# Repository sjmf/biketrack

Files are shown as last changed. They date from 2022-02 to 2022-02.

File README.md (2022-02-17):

# BikeTrack
A homebrew GPS Tracker using Teensy 3.x and SIM808.

This project aims to implement a basic GPS tracker with the above hardware. There
is a requirement that this runs from a battery, potentially using the bike dynamo 
to charge while riding.

In 2020 my bike was stolen from the roof of my car. Although I later found where it
was located, due to police incompetence it still has not been recovered. I bought
a new bike, and set about building an asset tracker with electronics hobbyist parts.

This repository contains WIP code and associated files for a basic asset tracking
system using GPS. As a work-in-progress, it is something I am tinkering with in
my spare time. While I'm good at finishing projects, I also tend to underestimate
the timescales and labour required to get there, so recognise the idiom that the 
last 10% takes 90% of the time...

## Hardware Selection
I received the [Adafruit SIM808](https://learn.adafruit.com/adafruit-fona-808-cellular-plus-gps-breakout/overview)
as a thoughtful christmas gift from my partner. I had a Teensy 3.1 in my electronics
storage, hence the selection of this microcontroller. The Sparkfun [MMA8452Q Accelerometer](https://www.sparkfun.com/products/12756)
was the only part I've had to actually buy so far!

The current status of this hardware is breadboarded up. Firmware is under implemetation.
The plan is to design and fabricate a simple PCB to solder these components directly on to, 
and 3d-print a housing/case using my [Prusa Mini+](https://www.prusa3d.com/product/original-prusa-mini-8/).

## Project Roadmap

- [x] Hardware Selection
  - [x] [Teensy 3.x](https://www.pjrc.com/store/teensy32.html)
  - [x] [Adafruit SIM808](https://learn.adafruit.com/adafruit-fona-808-cellular-plus-gps-breakout/overview)
  - [x] [MMA8452Q Accelerometer](https://www.sparkfun.com/products/12756)
- [ ] Firmware Implementation (breadboard)
  - [x] SIM808 [Proof of Concept](https://forums.adafruit.com/viewtopic.php?f=54&t=187767&p=910403)
    - [x] Power on programatically using KEY pin
    - [x] Cellular + GPS functionality
    - [x] Run from battery
  - [x] MMA8452Q Proof of Concept
    - [x] Interrupt-driven code PoC ([modified SparkFun Library](https://github.com/sjmf/SparkFun_MMA8452Q_Arduino_Library))
  - [ ] Low Power use on Teensy using [duff2013/Snooze](https://github.com/duff2013/Snooze)
  - [ ] Code Integration (see [Firmware Requirements](Requirements.md))
- [ ] Hardware implementation
  - [x] Breadboard PoC
  - [x] Schematic design
  - [x] PCB Design / Layout
  - [x] Order PCBs
  - [ ] Solder up
- [x] Serverside functionality
  - [x] SIM808 POST to server
  - [x] Store GPS points in [MongoDB Atlas](https://www.mongodb.com/cloud/atlas/)
  - [x] Retrieve GPX Track
  - [x] Plot GPX track in OpenLayers
  - [ ] Security (currently no authentication, no client SSL, replay attacks possible)
  - [ ] Add field 'segmentstart' to new track segments when storing
- [ ] Housing design
  - [ ] CAD housing for project
  - [ ] 3D-print case

## Gallery

Hardware progress. The devices on a breadboard:
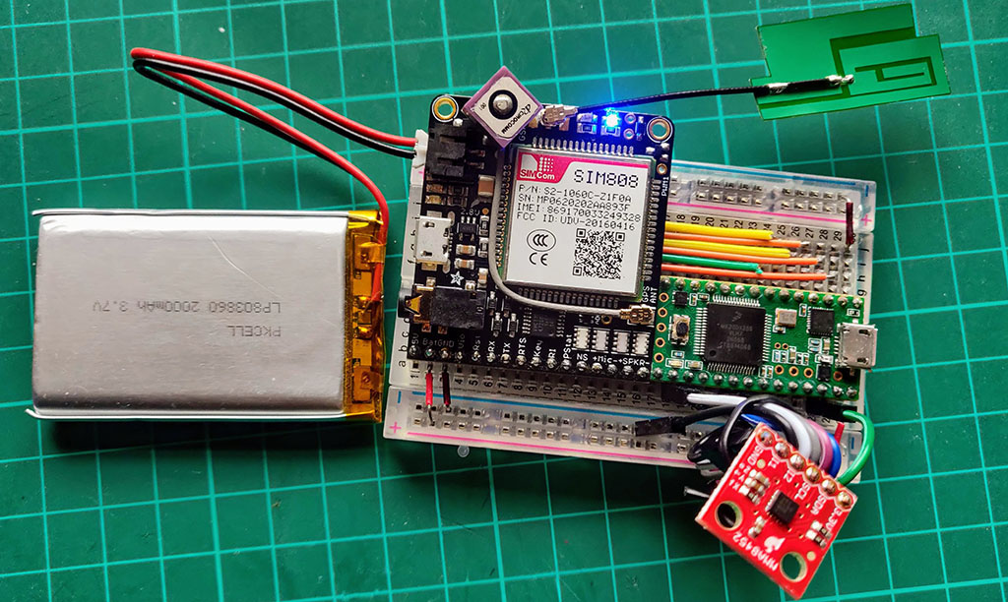
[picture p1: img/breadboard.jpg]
The tracker hardware on an electronics breadboard


Learning [Fusion 360](https://www.autodesk.co.uk/products/fusion-360/personal):
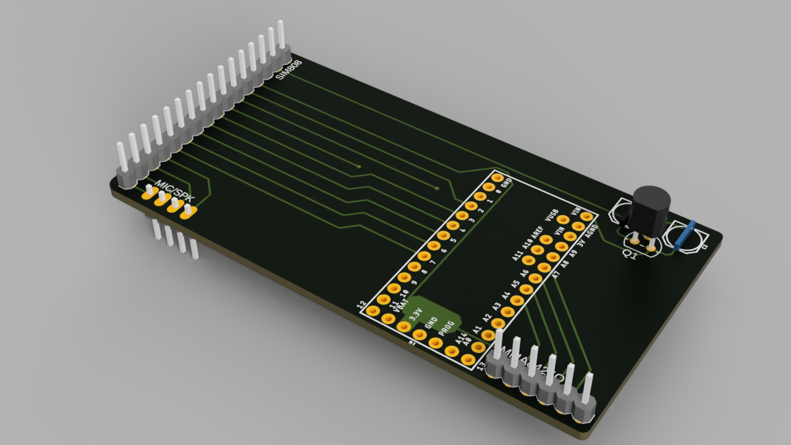
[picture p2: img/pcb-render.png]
A CAD rendering of the PCB


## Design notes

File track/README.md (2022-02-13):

# Server-side example application

This directory contains an example application in PHP, using Composer to 
install the [MongoDB Library](https://docs.mongodb.com/drivers/php/).
View the documentation at that link to install it, as it requires a low-level
API extension to be installed in your PHP CGI server.

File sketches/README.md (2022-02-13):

# Arduino sketches
Proof-of-concept and implementation Arduino sketches for the FONA and
accelerometer hardware.

## accel-interrupt
Uses a modified Sparkfun Library to read the MMA8452Q via the interrupt pin.
Install this library from [sjmf/SparkFun_MMA8452Q_Arduino_Library](https://github.com/sjmf/SparkFun_MMA8452Q_Arduino_Library)
by downloading it as a zip file, then click "Sketch > Include Library > Add .ZIP Library..."
within Teensyduino. Note that this lib acts as a replacement and will conflict with the original
Sparkfun Lib.

## track-gps
A basic implementation of the GPS tracking functionality using a state machine

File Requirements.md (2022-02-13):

# Firmware Requirements

This project needs to be low-power, low-data, and somewhat resilient. As such, this document examines
the firmware requirements needed to achieve this.

There are two modes of operation: low-accuracy, and high-accuracy.

__Low accurracy__ mode is when we've detected no movement. We're just letting the server know we're still here, and our battery level.
We may want a number of tries to get a GPS fix, and if we fail, just get gsmLoc instead. Then, send the battery level and go back to sleep.

__High accuracy__ mode is when we're moving. A second timer interrupt is configured to upload movement every 30s(~?). Keep all radios on!

## Setup
At setup, we do the following:

 - Initialise pins: set pinModes for I/O on FONA and Accelerometer
 - Hardware check. Are the peripherals present?
 - Hardware initialisation: run initialisation routines
 - Initialise interrupts: attachInterrupt for timers and accelerometer

## Main loop

Most of the time, we want to deep-sleep here.

The sleep will be interrupted and the loop will run when the following happens:

 - A timer interrupt happened
 - Movement happened

## States
Build a [transition table](https://www.adamtornhill.com/Patterns%20in%20C%202,%20STATE.pdf) for our state machine.

States to cover:

 - Trying to get first GPS fix
 - Got GPS first fix (have GPSdata)
 - Turn on GPRS radio (don't advance until active)
 - Transmit current position over HTTP
 - Shut down GPRS radio

We will want to keep the GPRS radio on while movement is happening.

## Interrupts

### Timers

It's time to wake up and check we have a fix. If we do, then upload that.

### Accelerometer movement

Sets the current time for last movement, and toggle the interrupt flag

## Questions

 - Does getGSMLoc() set AGPS data? Can we get a faster fix using it?

## Nice-to-haves

SMS command and control:
  - Ask to go into high-accuracy for a bit.
  - Set off a siren or buzzer (e.g. if I'm outside the thief's flat...)

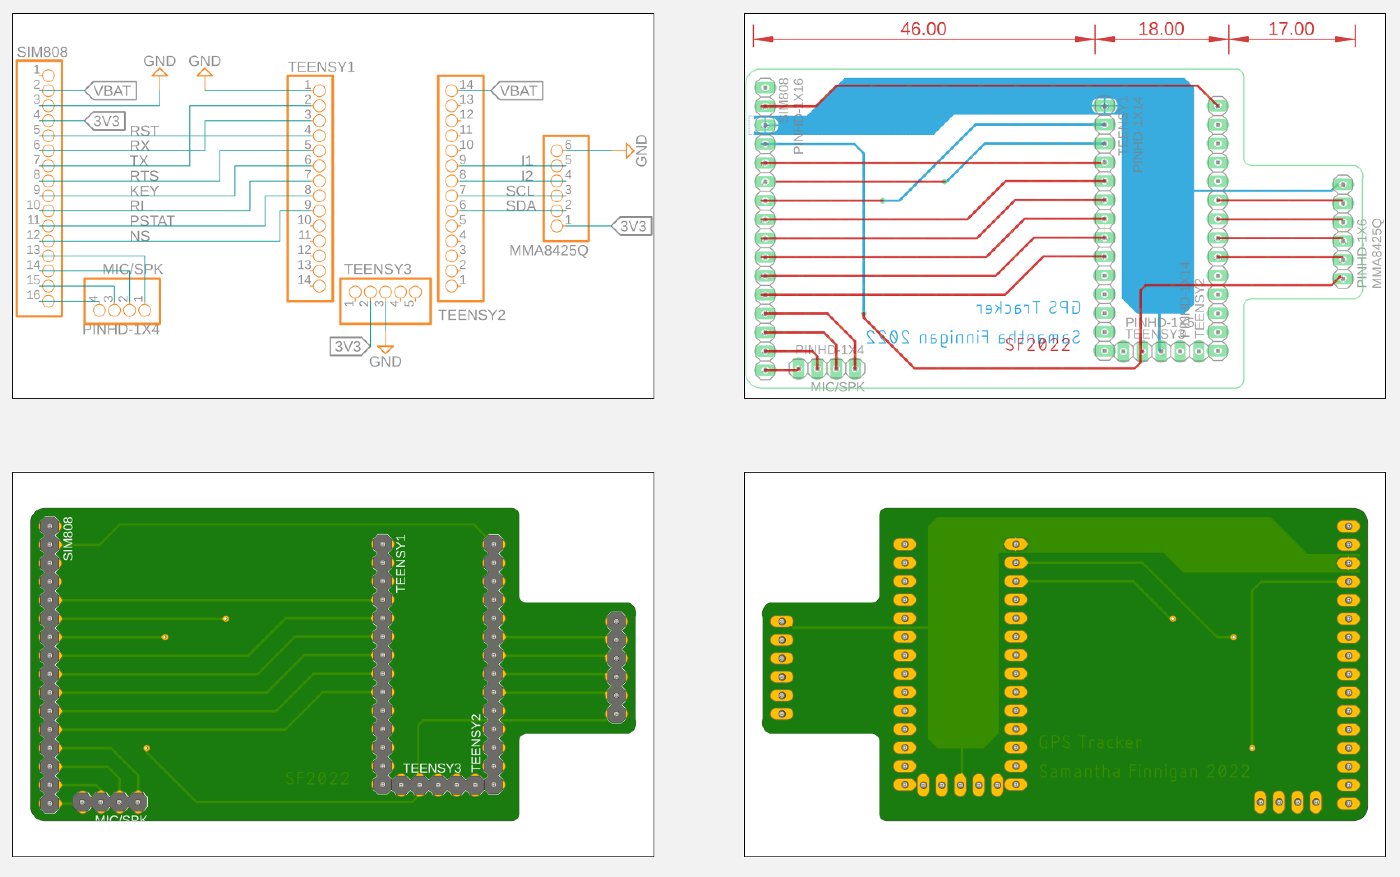
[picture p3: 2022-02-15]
img/schematic.png

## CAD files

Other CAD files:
hardware/tracker_schematic.f3z

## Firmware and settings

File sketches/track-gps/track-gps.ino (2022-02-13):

/**
 * GPS tracker using Adafruit FONA 808 cellular module
 * 
 * Uses boilerplate code from the Adafruit FONAtest.c example
 * 
 * @author Samantha Finnigan
 * @date 2021
 */
#include <SparkFun_MMA8452Q.h>

#include <avr/sleep.h>
#include "Adafruit_FONA.h"

// Configure input pins depending on platform:
#if (defined(__AVR__) || defined(ESP8266)) && !defined(__AVR_ATmega2560__)
#include <SoftwareSerial.h>

  // ESP8266 pins
  #define FONA_RST 14
  #define FONA_RX  12
  #define FONA_TX  13
  
  SoftwareSerial fonaSS = SoftwareSerial(FONA_TX, FONA_RX);
  SoftwareSerial *fonaSerial = &fonaSS;

#else
  // On Leonardo/M0/etc, others with hardware serial, use hardware serial!
  HardwareSerial *fonaSerial = &Serial1;
  
  // Teensy 3.1 hardware serial pins
  #define FONA_RX  0
  #define FONA_TX  1
  #define FONA_RST 2
#endif

#define FONA_RI  3
#define FONA_KEY 4
#define FONA_PS  5
#define TEENSY_LED 13

#define GPRS_APN  "giffgaff.com"
#define GPRS_USER "gg"
#define GPRS_PASS "p"

#define POST_URL "http://example.com/track/"
#define TRACK_MS 300000 // 5 minutes
#define IDLE_MS  10000
#define RETRIES  10

// Uncomment to disable LEDs, pins, etc
//#define LOW_POWER

char debug[128];

// Define for FONA 808/800
Adafruit_FONA fona = Adafruit_FONA(FONA_RST);

uint8_t type = FONA808_V2;

// State machine
typedef enum 
{
  GPS_INIT,
  GPRS_INIT,
  GPS_WAIT,
  HTTP_POST
} State;

State state = GPS_INIT;


/****************************************************************
 * Do program setup work: enable serial output, detect FONA board etc.
 * Runs once.
 */
void setup() {
  
  Serial.begin(115200);
  
  pinMode(TEENSY_LED, OUTPUT);
  pinMode(FONA_KEY, OUTPUT);
  pinMode(FONA_PS, INPUT);
  pinMode(FONA_RI, INPUT);
  
  turnFONAon();
  
  // Print module IMEI number.
  char imei[16] = {0}; // MUST use a 16 character buffer for IMEI!
  uint8_t imeiLen = fona.getIMEI(imei);
  if (imeiLen > 0) {
    Serial.print("Module IMEI: "); Serial.println(imei);
  }
  
  fona.setGPRSNetworkSettings(F(GPRS_APN), F(GPRS_USER), F(GPRS_PASS));
  
  // HTTPS not (currently?) working? https://forums.adafruit.com/viewtopic.php?f=19&t=59358
//  fona.setHTTPSRedirect(true); 
}


/****************************************************************
 * Main loop
 */
void loop() {
  char gpsdata[120] = "";
  char *buffer;
  char *url;
  int16_t stat = 0;
  int8_t retries = 0;
  
  while (1) {
    
    switch(state) {
      // Set up 
      case GPS_INIT:
        startGPS();
        state = GPRS_INIT;
        //break; // No need. Fall through.

      case GPRS_INIT:
        if(startGPRS()) { // Got home network association and GPRS OK!
          state = GPS_WAIT;
        } else {
          break; // Fall through if state progressed!
        }
        
      case GPS_WAIT:
        buffer = gpsdata;
        do {
          stat = getBatteryVoltage(buffer);
          delay(1000); // Wait for FONA to wake up
        } while (!stat);
        
        buffer = &buffer[stat];
        Serial.println(stat);
        
        strcpy(buffer, "gps=");       // 4 characters = 4 bytes,
        buffer = &buffer[4];          //    so advance buffer by 4...
        stat = getGPSLoc(buffer);     // Write after POST req variable
        
        // Wait for a fix...
        // If our GPS data starts (after position 4 (+ buffer offset)) '1980', 
        // then we have a cold boot and need to wait longer for a fix
        if(stat >=2) {
          state = HTTP_POST;
        } else {
          break;  // Break in else: otherwise, fall through.
        }

      case HTTP_POST:
        url = (char*)POST_URL;
        
        if(!httpPOST(gpsdata, url)) {
          // Weird unrecoverable network error stuff? Try again or reboot.
          if(retries > RETRIES) {
            softReset();
          }
          retries++;
          sprintf(debug, "Retries remaining: %d/%d; status: %d", RETRIES - retries, RETRIES, stat);
          Serial.println(debug);
          break;
        }
        
        state = GPS_WAIT;
        break;

//      case SHUTDOWN:
//        disableGPRS();
//        turnFONAoff();
//        break;
      
      default: break;
    }


    // Sleep length for GPS_WAIT is longer:
    if (state == GPS_WAIT) {
//      turnFONAoff();
      delay(TRACK_MS);
//      turnFONAon();
    } else {
      delay(IDLE_MS);
    }
    
    flashLED();
    idle();
  }
}


/****************************************************************
 * Start up Global Positioning Satellite receiver
 */
void startGPS() {
  // Turn GPS on
  Serial.println(F("Enabling GPS..."));
  if (!fona.enableGPS(true))
    Serial.println(F("Failed to enable GPS"));
  else
    Serial.println(F("GPS Enabled"));
}


/****************************************************************
 * Start up GPRS
 */
bool startGPRS() {
  uint8_t stat = checkNetStatus();

  // First, check if we're associated with the network:
  if(stat == 1 || stat == 5) {
    // Got network association OK, now try to enable GPRS:
    if (fona.enableGPRS(true)) {
      Serial.println(F("GPRS radio enabled"));
      return true;
    }
    
    Serial.println(F("Failed to enable GPRS"));
  }
  return false;
}


/****************************************************************
 * Turn off GPRS
 */
void disableGPRS() {
  // turn GPRS off
  if (!fona.enableGPRS(false))
    Serial.println(F("Failed to turn off"));
}


/****************************************************************
 * Check the data network association status
 */
int8_t checkNetStatus() {
  uint8_t stat = fona.getNetworkStatus();
  Serial.print(F("Network status "));
  Serial.print(stat);
  Serial.print(F(": "));
  
  if (stat == 0) Serial.println(F("Not registered"));
  if (stat == 1) Serial.println(F("Registered (home)"));
  if (stat == 2) Serial.println(F("Not registered (searching)"));
  if (stat == 3) Serial.println(F("Denied"));
  if (stat == 4) Serial.println(F("Unknown"));
  if (stat == 5) Serial.println(F("Registered roaming"));
  
  return stat;
}


/****************************************************************
 * Read the battery voltage and percentage
 * Writes 17 characters into the provided buffer
 * Returns the number of characters written
 */
uint8_t getBatteryVoltage(char *buffer){
  uint16_t vbat;
  if (fona.getBattVoltage(&vbat)) {
    sprintf(buffer, "vbat=%04u&", vbat); // 10 characters fixed width
  } else {
    Serial.println(F("Failed to read Batt"));
    return 0;
  }

  if (fona.getBattPercent(&vbat)) {
    sprintf(&buffer[10], "vpc=%02u&", vbat); // 7 chars fixed width
  } else {
    Serial.println(F("Failed to read Batt"));
  }

  Serial.println(buffer);
  return strlen(buffer);
}



/****************************************************************
 * Get a GPS location
 */
int8_t getGPSLoc(char gpsdata[]) {
  int8_t stat = gpsStatus();
  
  // If we have a fix, get our GPS location and store it in the passed char[] array!
  if(stat >= 2) {
    // Also log it to serial ;)
    fona.getGPS(0, gpsdata, 120);
    Serial.println(F("Reply in format: mode,fixstatus,utctime(yyyymmddHHMMSS),latitude,longitude,altitude,speed,course,fixmode,reserved1,HDOP,PDOP,VDOP,reserved2,view_satellites,used_satellites,reserved3,C/N0max,HPA,VPA"));
    Serial.println(gpsdata);
  }
  return stat;
}


/****************************************************************
 * GPS Status
 */
int8_t gpsStatus() {
  // check GPS fix
  int8_t stat;
  stat = fona.GPSstatus();
  if (stat < 0)
    Serial.println(F("Failed to query"));
  if (stat == 0) Serial.println(F("GPS off"));
  if (stat == 1) Serial.println(F("No fix"));
  if (stat == 2) Serial.println(F("2D fix"));
  if (stat == 3) Serial.println(F("3D fix"));
  
  return stat;
}


/****************************************************************
 * Do HTTP Post
 */
uint16_t httpPOST(char data[], char url[]) {
  // Post data to website
  uint16_t statuscode = 0;
  int16_t length;

  flushSerial();
  Serial.println(data);
  
  Serial.println(F("****"));
  
  
  if (!fona.HTTP_POST_start(url, F("application/x-www-form-urlencoded"), (uint8_t *) data, strlen(data), &statuscode, (uint16_t *)&length)) {
    Serial.print(F("Failed post to "));
    
    sprintf(debug, "Status: %d", statuscode);
    Serial.println(debug);
    return 0;
  }
  
  sprintf(debug, "Response body length: %d", length);
  Serial.println(debug);
  
  while (length > 0) {
    while (fona.available()) {
      char c = fona.read();

// Slow serial. Write directly to serial register on supported platforms
#if defined(__AVR_ATmega328P__) || defined(__AVR_ATmega168__)
      loop_until_bit_is_set(UCSR0A, UDRE0); /* Wait until data register empty. */
      UDR0 = c;
#else
      Serial.write(c);
#endif

      length--;
      if (! length) break;
    }
  }
  Serial.println(F("\n****"));
  fona.HTTP_POST_end();
  
  return statuscode;
}


/****************************************************************
 * Hush, now...
 * https://www.pjrc.com/teensy/low_power.html
 */
void idle() {
  set_sleep_mode(SLEEP_MODE_IDLE);
  noInterrupts();
  sleep_enable();
  interrupts();
  sleep_cpu();
  sleep_disable();
}


/****************************************************************
 * LED routines:
 */
void flashLED() {
#ifndef LOW_POWER
  digitalWrite(TEENSY_LED, HIGH);   // turn the LED on (HIGH is the voltage level)
  delay(200);                       // wait for a second
  digitalWrite(TEENSY_LED, LOW);    // turn the LED off by making the voltage LOW
#endif
}
void ledON() {
#ifndef LOW_POWER
  digitalWrite(TEENSY_LED, HIGH);
#endif
}
void ledOFF() {
#ifndef LOW_POWER
  digitalWrite(TEENSY_LED, LOW);
#endif
}


/****************************************************************
 * Pulse KEY pin for 2 seconds to power up/down module
 * Provides convenience methods which check PS pin first
 */
void _toggleFONA() {
  Serial.println("Pulling KEY pin...");
  delay(1000);
  digitalWrite(FONA_KEY, HIGH);
  delay(1000);
  digitalWrite(FONA_KEY, LOW);
  delay(2000);
  digitalWrite(FONA_KEY, HIGH);
  delay(1000);
}
uint8_t _getFONAPowerStatus() {
  return digitalRead(FONA_PS);
}
void turnFONAon() {
  if (! _getFONAPowerStatus()) {
    // Fona is off if FONA_PS is low
    Serial.println("Bringing FONA up...");
    ledON();
    _toggleFONA();
    
    ledOFF();
  } else {
    // FONA is already on!
    Serial.println("FONA is already on!");
  }

  // Bootstrap FONA
  fonaSerial->begin(4800);
  if (! fona.begin(*fonaSerial)) {
    Serial.println(F("Couldn't find FONA"));
    ledOFF();
    delay(100);
    softReset();
  }
}
void turnFONAoff() {
  if (_getFONAPowerStatus()) {
    // Fona is on if FONA_PS is high
    Serial.println("Putting FONA to sleep...");
    _toggleFONA();
  } else {
    // FONA is already off!
    Serial.println("FONA is already off!");
  }
}

/****************************************************************
 * Flush Serial
 */
void flushSerial() {
  while (Serial.available())
    Serial.read();
}

/****************************************************************
 * Soft reset Teensy
 */
#define SCB_AIRCR (*(volatile uint32_t *)0xE000ED0C) // Application Interrupt and Reset Control location
void softReset() {
  Serial.end();  //clears the serial monitor  if used
  SCB_AIRCR = 0x05FA0004;
}

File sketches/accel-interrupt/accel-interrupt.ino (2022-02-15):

// https://www.pjrc.com/teensy/interrupts.html
#include <avr/io.h>
#include <avr/interrupt.h>

#include <Wire.h>                 // Include Wire library for I2C
#include "SparkFun_MMA8452Q.h"    // Uses forked library for interrupt support. Install: https://github.com/sjmf/SparkFun_MMA8452Q_Arduino_Library
#include <avr/sleep.h>

#define MMA_PIN_INT1 20
#define MMA_PIN_INT2 21
#define TEENSY_LED 13

#define MOTION_THRESHOLD 0x10
#define MOTION_DEBOUNCE  0x30

MMA8452Q accel;

volatile uint8_t interrupt = 0;
uint8_t source = 0;

void setup() {
  pinMode(MMA_PIN_INT1, INPUT_PULLUP);
  pinMode(MMA_PIN_INT2, INPUT_PULLUP);
  pinMode(TEENSY_LED, OUTPUT);
  
  // put your setup code here, to run once:
  Serial.begin(115200);
  Wire.begin();
  
  // NB: maybe use accel.init() instead for fine-control of SCALE and DATA RATE. See Example7_OriginalDeprecated in SparkFun MMA lib
  if (accel.init(SCALE_4G, ODR_800) == false) {
    Serial.println("Not Connected. Please check connections and read the hookup guide.");
    while (1);
  }
  
  Serial.println("Setting up interrupts!");
  accel.setInterruptsEnabled(INT_FREEFALL_MOTION);
  accel.configureInterrupts(false, false); // Active HIGH (pulled high = interrupt). Push-pull configuration.
  accel.setInterruptPins(false, false, false, false, false, false); // True = pin 1 (here freefall_motion connected to MMA_PIN_INT1)
  accel.setupMotionDetection(MOTION_THRESHOLD, MOTION_DEBOUNCE); // motionThreshold, debounceCount

  // https://forum.pjrc.com/threads/42800-Teensy-Interrupts-for-Dummies
  attachInterrupt(digitalPinToInterrupt(MMA_PIN_INT1), isr, FALLING);
  
  Serial.println("Setup done");
}

void idle() {
  set_sleep_mode(SLEEP_MODE_IDLE);
  noInterrupts();
  sleep_enable();
  interrupts();
  sleep_cpu();
  sleep_disable();
}

void loop() {
  
  // put your main code here, to run repeatedly:
  if(interrupt) {
    Serial.print("Service Interrupt: ");
    if (accel.available()) {      // Wait for new data from accelerometer
      // Acceleration of x, y, and z directions in g units
      Serial.print(accel.getCalculatedX(), 3);
      Serial.print("\t");
      Serial.print(accel.getCalculatedY(), 3);
      Serial.print("\t");
      Serial.print(accel.getCalculatedZ(), 3);
      Serial.println();
    }

    printMotionSource();

    
    noInterrupts(); // cli();
    interrupt = 0;
    interrupts();   // sei();
  }

  idle();
}

void isr() {
  interrupt++;
  digitalWrite(TEENSY_LED, !digitalRead(TEENSY_LED));
}

void printMotionSource() {
  source = accel.readMotionSourceRegister();
    
#define BYTE_TO_BINARY_PATTERN "%c%c%c%c%c%c%c%c"
#define BYTE_TO_BINARY(byte)  \
  (byte & 0x80 ? '1' : '0'), \
  (byte & 0x40 ? '1' : '0'), \
  (byte & 0x20 ? '1' : '0'), \
  (byte & 0x10 ? '1' : '0'), \
  (byte & 0x08 ? '1' : '0'), \
  (byte & 0x04 ? '1' : '0'), \
  (byte & 0x02 ? '1' : '0'), \
  (byte & 0x01 ? '1' : '0') 

  Serial.printf("%d. calls. FF_MT_SRC: 0x%02x -- 0b" BYTE_TO_BINARY_PATTERN "\n", 
    interrupt, source, BYTE_TO_BINARY(source)
  ); 
}

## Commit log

2022-02-13 Add Teensyduino Proof-of-concept Sketches
2022-02-13 🗺 Add example server-side logging and query code using MongoDB
2022-02-13 🧐 Create example mongodb.json
2022-02-13 🛫 Update roadmap
2022-02-13 📄 Add some basic requirements
2022-02-15 🏞 Add progress images for documentation
2022-02-15 ⚙️ Add hardware schematics from Fusion 360
    [tracker_schematic.f3z]
2022-02-15 🕹 Change pins for better board layout
2022-02-15 📸 Add images to Readme.md
2022-02-17 🤖 Update schematic and add Gerber data
2022-02-17 🔦 Update README with CAD render
2022-02-17 🚧 Update project roadmap
